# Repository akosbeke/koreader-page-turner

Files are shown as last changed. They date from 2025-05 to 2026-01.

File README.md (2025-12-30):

# KOReader Page Turner

This project aims to give a hardware page turner for those using KOReader.

It takes advantage of the KOReader HTTP inspector plugin.

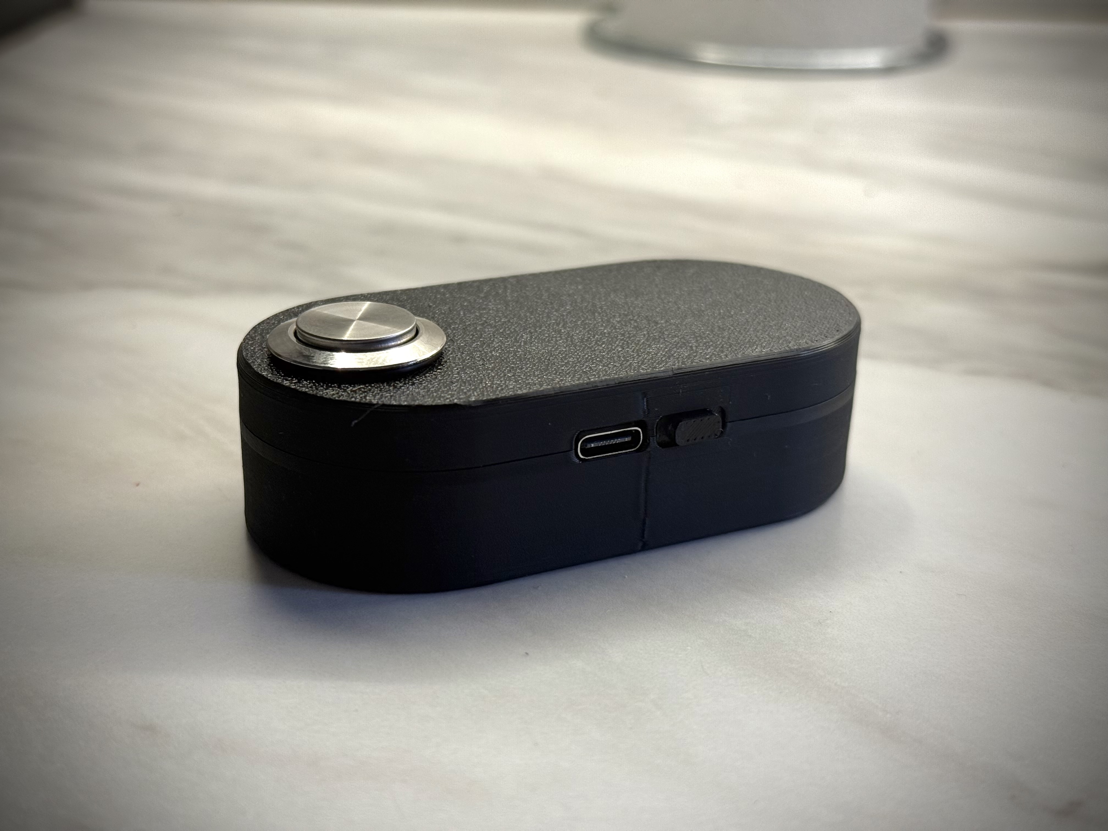
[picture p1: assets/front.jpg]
Front view


# Hardware

In order to make this project readily available for everyone I used popular modules and components.

## Bill of Materials

* LILYGO® T7 S3 ESP32-S3 ([Aliexpress](https://www.aliexpress.com/item/1005004777561826.html), [LILYGO®](https://lilygo.cc/products/t7-s3?variant=42490159464629))
* Momentary Button - 19mm, High head ([Aliexpress](https://a.aliexpress.com/_ExlqFZw)) - IMPORTANT!!! Order the 19mm variant as the design is built around that size.
* 103450 Lipo Battery 2000mAh ([Aliexpress](https://www.aliexpress.com/item/1005008129110763.html))
* 3 x 'M3' self tapping screw 10mm ([Aliexpress](https://www.aliexpress.com/item/4000982209705.html))

Some soldering is required but nothing crazy and I will provide a detailed guide for it.

The LILYGO board has a USB Type C port which can be used to program, and charge. It also has a battery charger module and port built in. Both the USB and power switch are exposed so they can be accessed once it's fully assembled.

# Software

The software is pretty simple and a [firmware.bin](bin/firmware.bin) is provided so you don't even need Platform.io set up.

With that being said, you can change/build it yourself using Platform.io.

## Easy Firmware Install

* Download the [firmware.bin](bin/firmware.bin) file
* Go to [ESPHome Web Tool](https://web.esphome.io)
* Click on `Connect`
* Pick the USB Serial port
* Click on Install
* Select the file you just downloaded
* Click on Install

## Configure

* After installing the firmware, the device will create an access point called `KoreaderPageTurnerAP`. Connect to it on your phone.
* A captive portal will pop up where you can enter your home WiFi credentials and your KOReader HTTP inspector details.
* After saving, the device will restart and connect to your WiFi.

You can later access the settings page by looking up the IP of the clicker on your router's settings page and open it in a browser.

You should reserve the IP of your e-reader in your router settings so you don't have to change again.

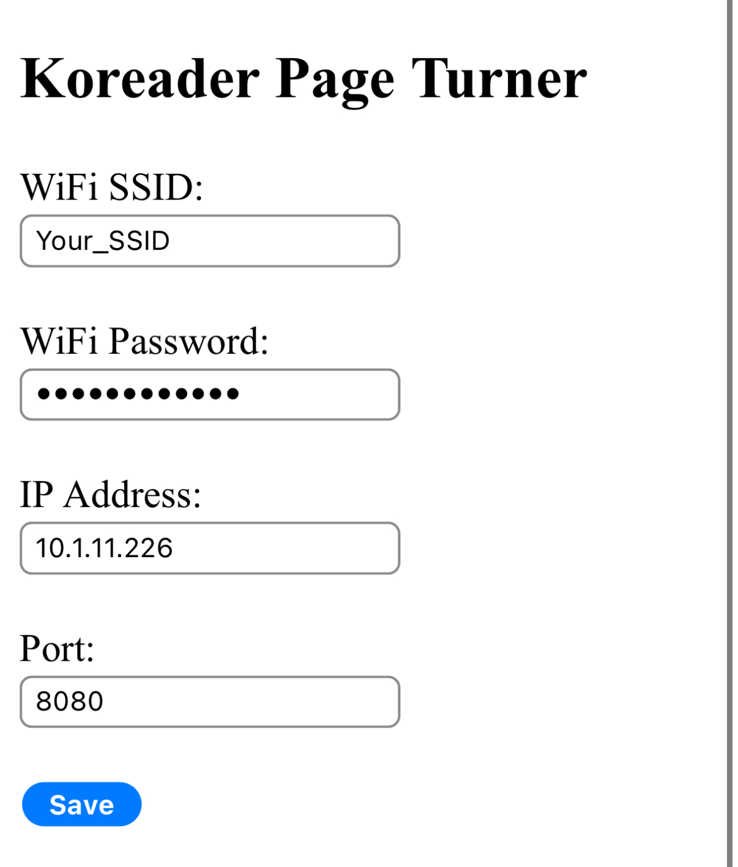
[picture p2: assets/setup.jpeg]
Setup


# 3D Case

Print it at home with any 3D printer. It consist of 3 parts:
* Top (holds the button and the microctonroller)
* Bottom (holds the battery)
* Switch (extends the onboard switch so you can switch the device off when not used)

You can find the STEP files under the `case` folder and the slice file on the [MakerWorld project](https://makerworld.com/en/models/1400135-koreader-page-turner-button#profileId-1451844)

# Assemble

The button should go in first. You have to turn the button itself as the nut cannot move.

I used hot glue to fix the battery and the microcontroller in place. They in their respective cavities.

Solder `GPIO4` to one side of the switch and `GND` to the other. 
If you have a battery like I did, you may need to switch the JST connector to the smaller one that came with the LILYGO microcontroller. It's just a matter of removing the shield tape, desolder, solder the new one, put back the tape.

Place the switch extender in between the top and bottom half (it goes in one correct way).

Screw in the 3 self tapping screws.

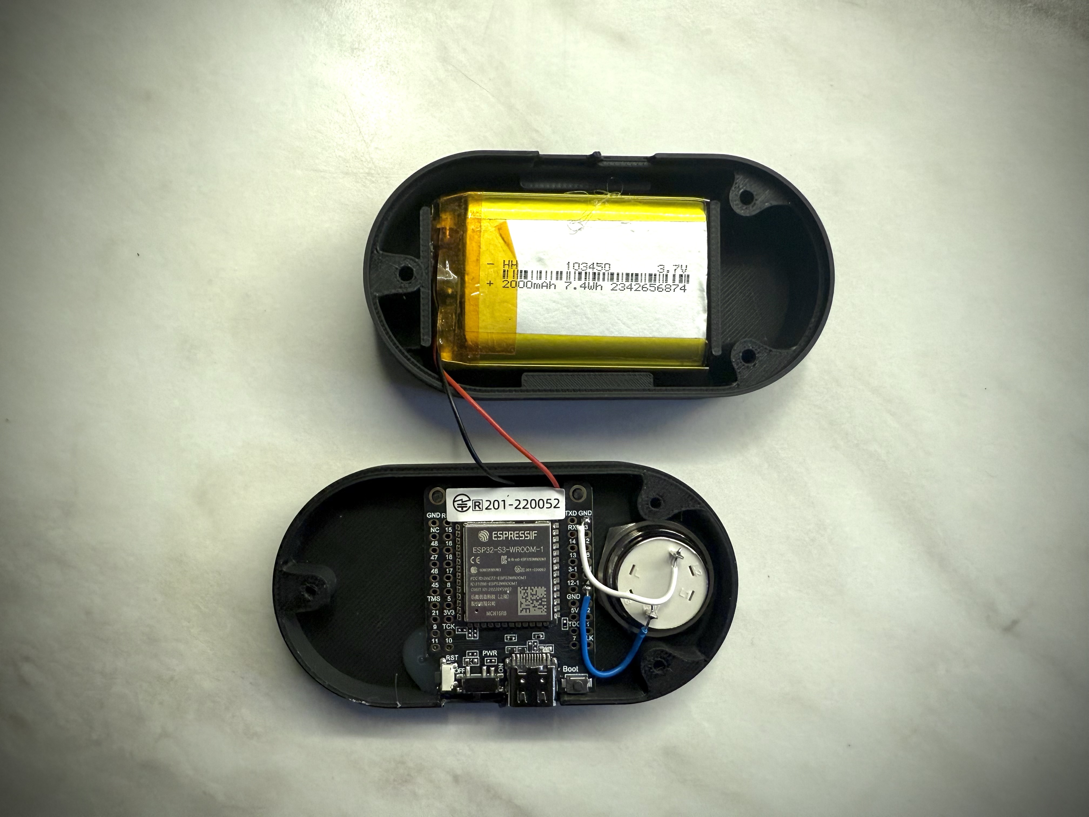
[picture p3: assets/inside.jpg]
Inside view

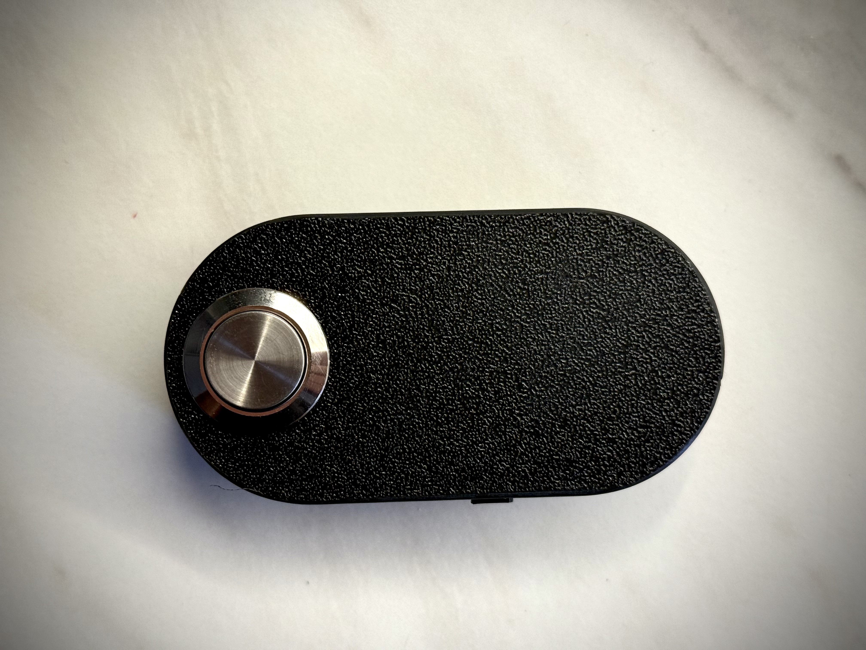
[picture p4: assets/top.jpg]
Top view


# KOReader

The only setting in KOReader that you need to change is enabling the HTTP Inspector plugin.

Go to `Tools/More Tools/KOReader HTTP inspectoar`.

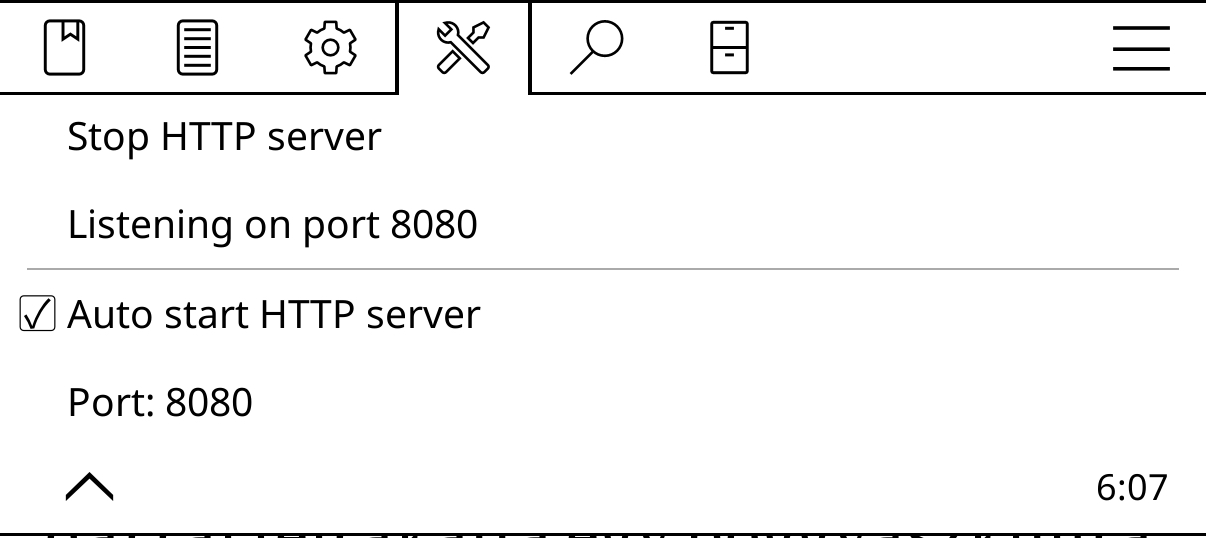
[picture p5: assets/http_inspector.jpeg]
Inspector


I suggest to turn on the Auto start checkbox so you don't have to deal with it each time.
The port can be whatever, but make sure you use the same on in the page turner setup process.

# Usage

This is gonna be a quick one. :)

| Action | Function |
| --- | --- |
| Single Click | Next Page |
| Long Click | Previous Page |
| 10 second click | Reset preferences |

When you reset the device, the access point will be opened again.

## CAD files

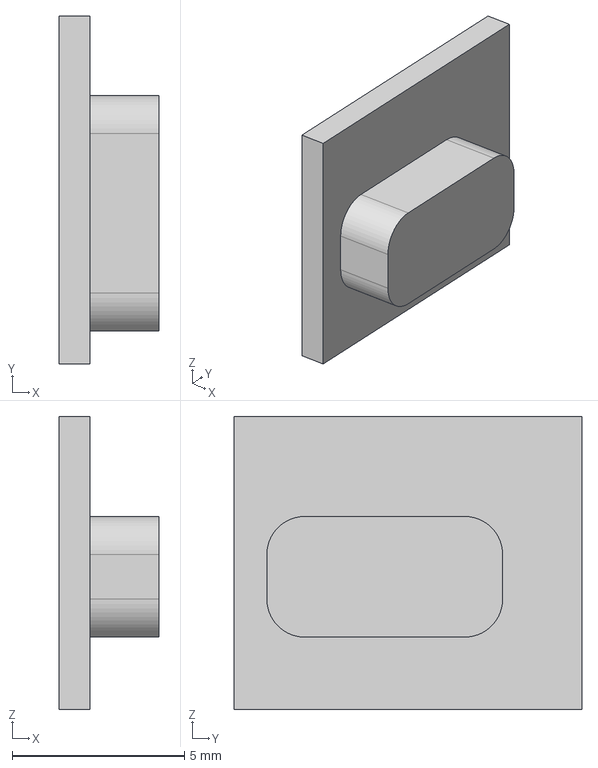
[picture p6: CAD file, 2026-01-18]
case/Switch.step
2.90 x 10.1 x 8.50 mm

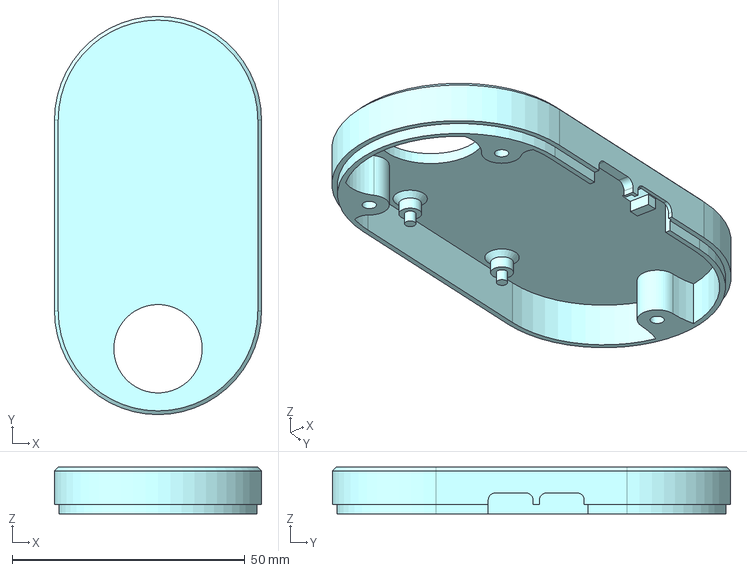
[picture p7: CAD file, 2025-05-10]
case/Top.step
44.5 x 85.6 x 10.0 mm

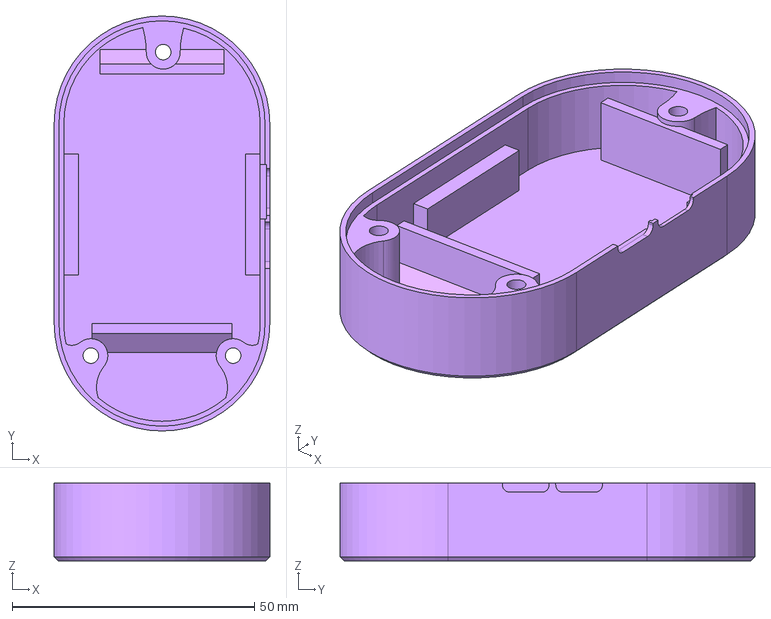
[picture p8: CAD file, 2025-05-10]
case/Bottom.step
44.5 x 85.6 x 16.0 mm

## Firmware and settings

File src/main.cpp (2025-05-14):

#include <Arduino.h>
#include <AsyncTCP.h>
#include <DNSServer.h>
#include <ESPAsyncWebServer.h>
#include <esp_wifi.h>
#include <Preferences.h>
#include <HTTPClient.h>

#define LED_PIN 17

Preferences preferences;

// Connection settings
const char *apSsid = "KoreaderPageTurnerAP";
const char *password = NULL; // no password

#define MAX_CLIENTS 1
#define WIFI_CHANNEL 6 // 2.4ghz channel 6 https://en.wikipedia.org/wiki/List_of_WLAN_channels#2.4_GHz_(802.11b/g/n/ax)

const IPAddress localIP(4, 3, 2, 1);   // the IP address the web server, Samsung requires the IP to be in public space
const IPAddress gatewayIP(4, 3, 2, 1); // IP address of the network should be the same as the local IP for captive portals
const IPAddress subnetMask(255, 255, 255, 0);

const String localIPURL = "http://4.3.2.1"; // a string version of the local IP with http, used for redirecting clients to config page

DNSServer dnsServer;
AsyncWebServer server(80);

// Hardware settings
#define MULTIACTION_PIN 4
#define MULTIACTION_MODE INPUT_PULLUP

void setUpDNSServer(DNSServer &dnsServer, const IPAddress &localIP)
{
// Define the DNS interval in milliseconds between processing DNS requests
#define DNS_INTERVAL 30

  // Set the TTL for DNS response and start the DNS server
  dnsServer.setTTL(3600);
  dnsServer.start(53, "*", localIP);
}

void startSoftAccessPoint(const char *ssid, const char *password, const IPAddress &localIP, const IPAddress &gatewayIP)
{
#define MAX_CLIENTS 1
#define WIFI_CHANNEL 6

  Serial.println("Could not connect to WiFi, starting Soft Access Point...");

  // Set the WiFi mode to access point and station
  WiFi.mode(WIFI_MODE_AP);

  const IPAddress subnetMask(255, 255, 255, 0);

  WiFi.softAPConfig(localIP, gatewayIP, subnetMask);
  WiFi.softAP(ssid, password, WIFI_CHANNEL, 0, MAX_CLIENTS);

  // Disable AMPDU RX on the ESP32 WiFi to fix a bug on Android
  esp_wifi_stop();
  esp_wifi_deinit();
  wifi_init_config_t my_config = WIFI_INIT_CONFIG_DEFAULT();
  my_config.ampdu_rx_enable = false;
  esp_wifi_init(&my_config);
  esp_wifi_start();
  vTaskDelay(100 / portTICK_PERIOD_MS); // Add a small delay

  Serial.println("Soft Access Point started, connect to:");
  Serial.println(ssid);
}

void startWifiOrAp()
{
  const char *apName = "KoreaderPageTurnerAP";
  const char *hostname = "KoreaderPageTurner";

  WiFi.hostname(hostname);
  WiFi.begin(preferences.getString("wifi_ssid", "").c_str(),
             preferences.getString("wifi_password", "").c_str());

  // Wait for connection
  Serial.println("Connecting to WiFi..");
  unsigned long startAttempt = millis();
  while (WiFi.status() != WL_CONNECTED && millis() - startAttempt < 15000)
  {
    delay(500);
    Serial.print(".");
  }

  if (WiFi.status() == WL_CONNECTED)
  {
    Serial.println("\nWiFi connected to:");
    Serial.println(preferences.getString("wifi_ssid", ""));
    Serial.println("IP address: ");
    Serial.println(WiFi.localIP());
  }
  else
  {
    startSoftAccessPoint(apSsid, password, localIP, gatewayIP);
  }
}

String getConfigPage()
{
  String wifi_ssid = preferences.getString("wifi_ssid", "");
  String wifi_password = preferences.getString("wifi_password", "");
  String ip = preferences.getString("ip", "");
  String port = preferences.getString("port", "8080");

  String html = R"rawliteral(
    <!DOCTYPE html>
    <html>
    <head>
      <meta charset="UTF-8">
      <title>Koreader Page Turner Settings</title>
      <meta name="viewport" content="width=device-width, initial-scale=1.0">
    </head>
    <body>
      <h2>Koreader Page Turner</h2>
      <form method="POST" action="/save">
        <label for="wifi_ssid">WiFi SSID:</label><br>
        <input type="text" id="wifi_ssid" name="wifi_ssid" value=")rawliteral" +
                wifi_ssid + R"rawliteral("><br><br>
        <label for="wifi_password">WiFi Password:</label><br>
        <input type="password" id="wifi_password" name="wifi_password" value=")rawliteral" +
                wifi_password + R"rawliteral("><br><br>
        <label for="ip">IP Address:</label><br>
        <input type="text" id="ip" name="ip" value=")rawliteral" +
                ip + R"rawliteral("><br><br>
        <label for="port">Port:</label><br>
        <input type="text" id="port" name="port" value=")rawliteral" +
                port + R"rawliteral("><br><br>
        <input type="submit" value="Save">
      </form>
    </body>
    </html>
  )rawliteral";

  return html;
}

void setUpWebserver(AsyncWebServer &server, const IPAddress &localIP)
{
  // Required
  server.on("/connecttest.txt", [](AsyncWebServerRequest *request)
            { request->redirect("http://logout.net"); }); // windows 11 captive portal workaround
  server.on("/wpad.dat", [](AsyncWebServerRequest *request)
            { request->send(404); }); // win 10

  // Background responses: Probably not all are Required, but some are. Others might speed things up?
  // A Tier (commonly used by modern systems)
  server.on("/generate_204", [](AsyncWebServerRequest *request)
            { request->redirect(localIPURL); }); // android captive portal redirect
  server.on("/redirect", [](AsyncWebServerRequest *request)
            { request->redirect(localIPURL); }); // microsoft redirect
  server.on("/hotspot-detect.html", [](AsyncWebServerRequest *request)
            { request->redirect(localIPURL); }); // apple call home
  server.on("/canonical.html", [](AsyncWebServerRequest *request)
            { request->redirect(localIPURL); }); // firefox captive portal call home
  server.on("/success.txt", [](AsyncWebServerRequest *request)
            { request->send(200); }); // firefox captive portal call home
  server.on("/ncsi.txt", [](AsyncWebServerRequest *request)
            { request->redirect(localIPURL); }); // windows call home

  // return 404 to webpage icon
  server.on("/favicon.ico", [](AsyncWebServerRequest *request)
            { request->send(404); }); // webpage icon

  // Serve Basic HTML Page
  server.on("/", HTTP_ANY, [](AsyncWebServerRequest *request)
            {
		AsyncWebServerResponse *response = request->beginResponse(200, "text/html", getConfigPage());
		response->addHeader("Cache-Control", "public,max-age=31536000");  
		request->send(response);
		Serial.println("Config page served"); });

  // Handle form submission
  server.on("/save", HTTP_POST, [](AsyncWebServerRequest *request)
            {
    String wifi_ssid;
    String wifi_password;
    String ip;
    String port;
    // If any of the parameters are missing, redirect to the config page
    if (!request->hasParam("wifi_ssid", true) || !request->hasParam("wifi_password", true) ||
        !request->hasParam("ip", true) || !request->hasParam("port", true))
    {
      Serial.println("Missing parameters, redirecting to config page");
      request->redirect(localIPURL);
      return;
    }
    // Get the parameters
    wifi_ssid = request->getParam("wifi_ssid", true)->value();
    wifi_password = request->getParam("wifi_password", true)->value();
    ip = request->getParam("ip", true)->value();
    port = request->getParam("port", true)->value();

    // Save the parameters to preferences
    preferences.putString("wifi_ssid", wifi_ssid);
    preferences.putString("wifi_password", wifi_password);
    preferences.putString("ip", ip);
    preferences.putString("port", port);

    request->send(200, "text/plain", "Settings saved. Restarting...");

    delay(1000);
    ESP.restart(); });

  server.onNotFound([](AsyncWebServerRequest *request)
                    {
		request->redirect(localIPURL);
		Serial.print("onnotfound ");
		Serial.print(request->host());	
		Serial.print(" ");
		Serial.print(request->url());
		Serial.print(" sent redirect to " + localIPURL + "\n"); });
}

void resetPreferences()
{
  preferences.clear();
  preferences.end();
  Serial.println("Preferences cleared, restarting...");

  delay(1000);
  ESP.restart();
}

void turnPage(int direction)
{
  HTTPClient http;

  // Sanitize the IP: remove "http://", "https://", and trailing "/"
  String ip = preferences.getString("ip", "");

  // Remove "http://" or "https://" if present
  if (ip.startsWith("http://") || ip.startsWith("https://"))
  {
    ip = ip.substring(ip.indexOf("//") + 2); // Skip past "http://" or "https://"
  }

  // Remove trailing "/" if present
  if (ip.endsWith("/"))
  {
    ip = ip.substring(0, ip.length() - 1);
  }

  String url = "http://" + ip + ":" + preferences.getString("port", "8080") + "/koreader/event/GotoViewRel/" + String(direction);

  Serial.println("Turning page: " + url);

  // Send the HTTP request
  http.begin(url);
  int httpResponseCode = http.GET();

  if (httpResponseCode > 0)
  {
    String response = http.getString();
    Serial.println("Response: " + response);
  }
  else
  {
    Serial.println("Error on HTTP request");
  }

  http.end();
}

void handleMultiaction()
{
  // click: on for at most 300ms
  // long click: on for at least 300ms but less than 2000ms
  // super long click: on for at least 10000ms

  // Handle the button press
  if (digitalRead(MULTIACTION_PIN) == LOW)
  {
    unsigned long startTime = millis();
    while (digitalRead(MULTIACTION_PIN) == LOW)
    {
      delay(10);
    }
    unsigned long duration = millis() - startTime;

    if (duration < 300)
    {
      // Next page on click
      turnPage(1);
    }
    else if (duration < 10000)
    {
      // Previous page on long click
      turnPage(-1);
    }
    else
    {
      Serial.println("Super long click detected");
      resetPreferences();
    }
  }
}

void startPreferences()
{
  preferences.begin("koreader", false);

  if (!preferences.isKey("wifi_ssid"))
  {
    preferences.putString("wifi_ssid", ""); // Set default ssid
  }

  if (!preferences.isKey("wifi_password"))
  {
    preferences.putString("wifi_password", ""); // Set default password
  }

  if (!preferences.isKey("ip"))
  {
    preferences.putString("ip", ""); // Set default IP
  }

  if (!preferences.isKey("port"))
  {
    preferences.putString("port", "8080"); // Set default port
  }
}

void setup()
{
  Serial.setTxBufferSize(1024);
  Serial.begin(115200);

  pinMode(LED_PIN, OUTPUT);
  digitalWrite(LED_PIN, HIGH);

  delay(1000); // Wait for the Serial to initialize

  pinMode(MULTIACTION_PIN, MULTIACTION_MODE);

  startPreferences();

  // Print a welcome message to the Serial port.
  Serial.println("\n\nStarting up...");
  Serial.printf("%s-%d\n\r", ESP.getChipModel(), ESP.getChipRevision());

  startWifiOrAp();

  setUpDNSServer(dnsServer, localIP);

  setUpWebserver(server, localIP);
  server.begin();

  Serial.print("\n");
  Serial.print("Startup Time:");
  Serial.println(millis());
  Serial.print("\n");
}

void loop()
{
  dnsServer.processNextRequest();
  delay(DNS_INTERVAL);
  handleMultiaction();
}

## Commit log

2025-04-19 Updated parts list to use the T7 S3 board
2025-05-09 finished case, updated firmware
    [Bottom.step, Switch.step, Top.step]
2025-05-10 Soldering instructions
2025-05-10 Screw tolerances
    [Bottom.step, Top.step]
2025-05-14 fixed super long press duration
    [main.cpp]
2025-12-30 Fixed button link
2026-01-18 new switch design (hopefully JLC compatible)
    [Switch.step]
